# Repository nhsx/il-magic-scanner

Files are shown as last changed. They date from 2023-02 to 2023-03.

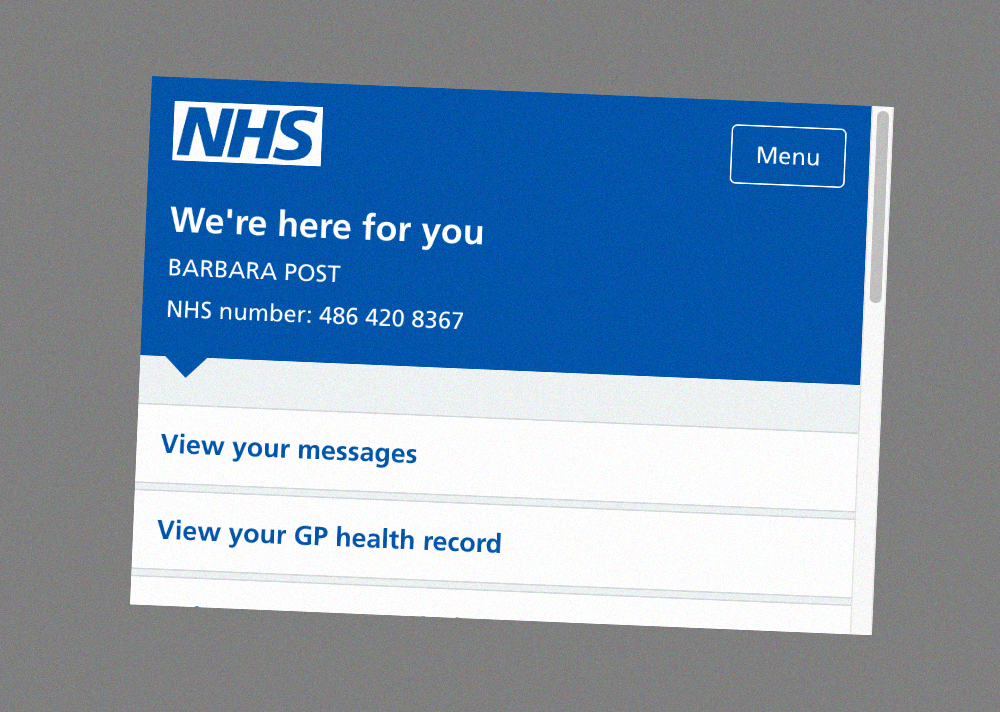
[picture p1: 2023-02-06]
piscanner/fakes/scan.png

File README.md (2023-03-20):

# The Magic Scanner

In this project, we built a portable scanner to test the idea of
scanning patients in to a hospital Patient Administration
System (PAS) with their phone without having to make changes to
the NHS App. The scanner takes an picture of the app home screen,
processes the image using optical character recognition (OCR),
and outputs the text in a format that can be easily consumed by
the PAS. We used a Raspberry Pi and a Pi camera module to build
the scanner, and trained the OCR model using the PyTesseract
library.

We were able to demonstrate that it is possible to build a
scanner like this with a small team on a tight timeline. The
project also highlighted the range of capabilities, equipment,
skills, and tooling required to build such a device, which could
be useful for future projects. However, further testing is needed
to assess the reliability of the scanner in practical use, and
the OCR model may need to be retrained with better training data
specifically to address potential ethnic bias issues.

## Setting The Scene

When you walk into A&E, the very first interaction you will have is
with the triage desk.  The hospital needs to know who you are.  Apart
from any administrative checkpointing, what the hospital want at that
point is a route in to your medical records.

The conversation that tells A&E who you are sounds simple, but it can
hide frustrating complexity.  Just the first question they'll ask -
what is your name? - can go down a rabbit-hole of misheard accents,
uncommon spellings, and unexpected cognitive difficulties.

Obviously a name alone isn't enough to identify someone.  They'll ask
for your date of birth, too, but even then, clinical mistakes have
been made where the same name and birthdate are shared by two
individuals.

To ensure they have identified *you*, and not someone else who happens
to have your name and birthday, what they really want is your NHS
Number.  But it is a rare patient who will know that off the top of
their head, or who will bring a GP letter with them to A&E.

Our hypothesis was this: if we can scan the information that the
triage desk wants out of the patient's phone, rather than have them
narrate it, we can solve three problems: first, the slow, face-to-face
"no, spelled with an 'E', two 'L's" conversation is short-cut; second,
we can bring additional information to the interaction in the form of
the NHS Number; and third we can get it right first time.

### The Patient ID QR Code

We want the NHS App to present a QR code containing the relevant
information, on the home screen.  QR scanners pretend to be a USB
keyboard: when you scan a QR code, to the computer it's as though
someone was sat there typing in the data encoded in the QR code.
And when you sign in to the NHS App with an NHS Login that is
sufficiently assured, it has all the information we want to
present. All the technical parts are straightforward.

However, if we want to make a change in the NHS App, that
effectively means rolling it out nationally.  We don't have the
cohorting ability to only roll out the QR code to people who are
going to turn up at a specific A&E: in general people don't
schedule falling off their ladders for us, convenient though that
would be.  That means we'd be introducing a potentially confusing
feature into the system before anyone could either explain what
it was.

Without being able to get a QR code into the NHS App itself as a
trial, the next most obvious option is that we stand up a
parallel service to generate the QR code.  This service would be
fronted by NHS Login, so people could use exactly the same
credentials as they use for the NHS App, and it as only purpose
would be to put a scannable code on the phone's screen.  This
would be technically simple to build and operate, but it turns
out that there's no way to implement this without causing a new
delay as the user signs in to this new service.  Using the same
credentials doesn't grant access to biometric login.

So this approach is largely ruled out.  We can't risk making things
worse otherwise no hospital is going to be interested in helping us to
run the trial.

### Or Not

And that's how we end up with this repository.  The fundamental
question we want to answer has nothing to do with QR codes, and
everything to do with the ergonomics of scanning the phone.  As long
as we can test "patient approaches desk, scans phone, is signed in"
and the timings around it, it doesn't matter what's shown on the
phone's screen.

So, we thought, why don't we just read the data off the home screen of
the app?  It has the name and the NHS Number, it's a known layout.
Can we design a scanner which will pluck that off the screen and
present it as though it *was* scanned by a barcode reader?

This repository is the code, CAD, data, and documentation of that
scanner.

## The Magic Scanner Operating Principle

We know that the scanner needs to:

1. Take a photo of the screen
2. Identify where the data we want is
3. Do some character recognition to turn right parts of the photo into text
4. Send that text to a USB host, as fake keypresses

And it has to do all that in a short enough time period that the
reception staff don't get annoyed with it or think it's broken; and it
has to be cheap enough that we'd be able to build a few of them
without breaking the bank.

Of all the steps, step 2 intrigued me the most.  That sort of object
recognition and bounding box extraction is a classic machine learning
task, and how well we could perform that job would put a limit on the
quality of data that the scanner would present to the user.

My first thought was to give a Raspberry Pi a try.  They have several
things going for them, most importantly for this project a) good
camera and USB gadget support; b) excellent software availability and
community activity; and c) I had a Pi Zero 2 sat next to me.

The importance of point c) shouldn't be underestimated.  We needed to
demonstrate that we could build a working prototype to test the
software and the ergonomics in days, not weeks, and having hardware
available off-the-metaphorical-shelf enabled us to go from idea to
first physical prototype between the Thursday of one week and Tuesday
the next.  Further refinement and a mk2 followed.

There were questions in my mind while making that choice, though: for
instance, would the processor in the Zero 2 have enough power to run
the machine learning model?

## The Build

### Physical Shell: the Mk1

Unfortunately the licensing situation in this project doesn't let me
share the original FreeCAD model itself, but I've put the `.step` file
[here](cad/piscanner-mk1.step) and the `.stl` (which github will
render for you as a pretty picture) [here](cad/piscanner-mk1.stl).
The reason is that the CAD model has a dependency on some third party
`.step` files that I don't have a licence to distribute.  When I get a
chance to come back and clean up the dependencies I will be able to
share the FreeCAD document, but until then, this is the best I can do.

There are a couple of things to note about the design of the mk1, both
good and bad.

#### 1. The Trigger Mechanism

I needed a button press to trigger taking the photo and processing it.
In my first version I thought it best to hide the button and see if I
could make the physical interaction as simple as possible.  In this
version there is a pair of buttons mounted under the window that the
Pi's camera peers through, such that when you press the phone
face-down onto the window, the window frame flexes and allows contact
to be made.  It's a mechanism which puts the phone screen at a
well-controlled distance from the camera lens.  This is important,
because the Pi Camera Module v2.1 is fixed focus.  They come from the
factory with a focal point out at infinity, and need to be refocused
to take good pictures of close objects.  The scanner needs not to be
too tall so I refocused the lens almost as close as I could, but until
I'd built the thing I didn't have a good way to check how much depth
of field I had to work with.  So this mechanism let me ensure that the
screen was in a precise place when the buttons were pressed.

If I were to build this mechanism again, there is a change I'd make in
that the current design puts the buttons on top of a pair of towers
attached to the base.  That attachment point is fine - I intentionally
wanted to be able to pull all the electronic guts out without too much
stress because I knew I was likely to want to change it around - but
the change I would make is to make the towers removable.  The distance
you need to depress the buttons I used to get a contact is sub-mm, and
the dimensional stability of the 3d printing process I used to make
the shell isn't great for this sort of design.  I wanted to be able to
swap out the towers to tweak their heights so the offset from the
flexible frame was better, but couldn't.

#### 2. The Absence Of Any Feedback Whatsoever

In the time available I just didn't have the opportunity to put any
status lights or readouts on the outside of the device.  I knew how I
was going to, it just fell outside the scope of a quick prototype
whose purpose was to prove the data pathway.

#### 3. The Raspberry Pi mounting

Rather than figure out the dimensions of a raspberry pi zero, I
figured that I could just reuse an existing case and clamp that into
place, giving me a single thing to position correctly on the base of
the scanner than having to worry about separately mounting the pi and
its attached camera.

This was a mixed blessing: the
[case](https://www.raspberrypi.com/products/raspberry-pi-zero-case/)
obviously fits the parts perfectly, but is a rather interesting shape,
which made cutting an accurate slot for it in the model something of a
challenge.  If I'd had a rather more rectilinear case to hand I would
have used that instead and simplified the job.

#### 4. Other flaws

In my rush, I underestimated how much clearance a USB plug needs.
There's not nearly enough clearance inside this body for a
conventional USB-micro plug to fit, and I ended up cutting a hole in
the wall for the USB keyboard cable.

There are a few other design details I could have done better and
suspected were a problem at the time, but sort of got away with.  The
mating interface between the base and the upper shell made the upper
hard to 3d print, for instance, and the attachment point for the
flexible window frame didn't have enough vertical bracing so the angle
of the window was dependent on the tightness of the bolts holding it
on.  Not ideal.

Purely by chance, at no point in the lifespan of the mk1 did I need
access to the SD card.  Lacking any way of getting at it which
wouldn't involve a complete disassembly was a conscious choice, but
one I would rectify later.

### Machine Learning

The scanner needs to be able to pull out small, specific chunks of the
pictures it takes, so that it can feed them to optical character
recognition software.  As I said above, this is an absolutely classic
machine learning task, but just knowing that it's possible is a world
away from having a working implementation that does the thing when you
press the button.

I simplified the problem of going from idea to implementation by
restricting the type of model I would look at to the YOLO family.
These are very fast, accurate enough object recognising neural network
systems that are popular enough in the industry that the tooling and
support around them is very good.  This meant that I had a choice of
implementation tooling.

Based on the availability of samples and documentation, I picked
`darknet` as a training platform and, initially, as the inference
platform that the scanner would execute when the button was pressed.

There is a terraform script for provisioning an AWS GPU instance (I've
picked `g3s.xlarge` as the cheapest spot instance size available) in
[here](gpu-terraform). It takes care of grabbing the
`darknet` source and building it.  Note that it *also* provisions a
smallish jump host as a non-GPU instance so that you can have a stable
jumping-off point that's not so expensive to run.

#### Model Selection

To cut a short story even shorter, given the time constraints I didn't
want to mess about trying to find a network architecture that would
work, I needed to pick something off the shelf that I could reuse
without too much hassle and would have enough power, and the right
inputs and outputs, for the task.  The YOLO family of network
architectures fit the bill, and specifically the YOLOv4-tiny variant
looked like it would have the performance characteristics we need.
It's also popular enough that there is a lot of guidance available
online for using it. There's a premade `darknet` config for it, so it
looked like it would be reasonable to start there and only change that
decision if it turned out either to be too slow, or not accurate
enough.

#### Training Data

We want the network to be able to put a bounding box around two items
of text on the phone screen: the patient's name, and their NHS number.
Given the constraints of the physical device, there's actually not
much variation we should expect in the pictures we'll be putting
through the network.  The home screen of the NHS App is very
constrained, visually speaking: it's a consistent font, there are very
consistent markers around the image, colours should only be in a
certain range, and so on.  That makes the job of putting together a
training data set simpler than it might otherwise be.

We're also helped here by a very useful technical detail: the NHS App
is (to simplify slightly) just a web site.  You can visit the site
online in a browser, and you can view the source.  If you resize the
browser window to be mobile phone shaped, it renders the same as if it
was on a phone.

So, I did that, grabbed the resulting web page, and saved it.  I then
edited the HTML to replace my name and NHS number with [python
template
markers](https://docs.python.org/3/library/string.html#template-strings).
That enabled [this
script](training-data-generation/generate_sample_html.py) to generate
an arbitrarily large number of fake NHS App home screens, each with
their own name and number.

Next, I used [this
script](training-data-generation/generate_screenshots.py) to take
screenshots of each fake with
[selenium](https://selenium-python.readthedocs.io/).  It's not just
the screenshot you need, though: to train the network to put the
bounding box in the right place, you also need to capture where the
bounding box is.  Fortunately that's made available by the browser
API, so we can directly read the bounding box out and save it to a
JSON file.

If you've been following along, you'll now have a directory full of
screenshots of the NHS App homepage, along with the bounding boxes of
where the information we want is.  That's all well and good, but we
need our scanner to be robust to the sorts of noise and distortion
that taking a photo of a phone screen under only semi-controlled
conditions will be subject to.  For this, I leaned on the
[albumentations](https://albumentations.ai/docs/#getting-started-with-albumentations)
tool.  [This
script](training-data-generation/generate_augmentations.py) is what
drives it, and you can see the list of different types of distortion
it applies for me:

```
[
    A.ShiftScaleRotate(shift_limit=0.0625,
                       scale_limit=0.5,
                       rotate_limit=10,
                       border_mode=cv2.BORDER_CONSTANT, value=(128,128,128),
                       p=0.75),
    A.GaussNoise(),
    A.Blur(blur_limit=3),
    A.OneOf([
        A.OpticalDistortion(p=0.3),
        A.GridDistortion(p=0.1),
    ], p=0.2),
    A.OneOf([
        A.CLAHE(),
        A.RandomBrightnessContrast(0.5)
    ], p=0.3),
    A.HueSaturationValue(p=0.3)
]
```

So that's a selection which simulates a few different ways the phone
can be out of position, or registering funny colours, or dirty, and so
on.

I generated many, many training images.  90,000, in fact.  This turned
out to be far too many to be practical and far more than was needed,
but at that point I reasoned that it was better to aim high because I
could always use a subset.

#### Training

Mechanically, the process of training was a matter of uploading the
training data into AWS and getting it onto a GPU instance, then just
running `darknet` with the right parameters.  A word to the wise:
generate the training data where you're going to do the training.
Don't put yourself in the position of needing to upload 5GB of images
over residential broadband.

ANYWAY.

The YOLOv4 architecture learned from this dataset *fast*.  Fast is
relative, but I had a usable network for testing with in half an hour
or so, and in slightly more than an hour `darknet` reported it was
done. Nowhere near the overnight runs that I was expecting.

From this I can intuit that the YOLOv4 architecture is *dramatically*
overpowered for this use case.  The question is whether this matters.
More on this shortly.

### USB Tomfoolery

Taking a brief break from the world of machine learning, there are a
couple of prosaic interface concerns which I needed to deal with.  One
of these is the need to replicate the data flow of a handheld QR code
scanner: to get the data across a USB cable, as though typed into a
keyboard.

Fortunately, making this simple is the Raspberry Pi Zero 2 hardware.
It has two micro-USB ports, one of which supports USB-OTG, which is
what a USB port needs to support if you want to connect it as a USB
*device*, rather than as a USB *host*.  Once set up as a USB gadget,
whether the USB host at the other end of the USB cable is detected as
a hard drive, a modem, or a keyboard is a matter of software
configuration.

Now, that's only half of the story.  When you think of sending data
and pretending to be a keyboard, it's clear that you can't just send
arbitrary data.  You can't send a `NULL`, for instance: there's no key
for that on the keyboard.  So we need a conversion that takes data,
and converts it into the corresponding keypresses.  Fortunately for
our purposes, the conversion is easy in that we only need to be able
to send things that are typeable: a name, a number, and some spaces.

In [this repository](https://github.com/nhsx/il-keebd) is a service
that runs on the raspberry pi whose job it is to take data (from
something else running on the machine), strip out anything it can't
pass on, and convert the remainder into keypresses.  It's not very
general, in the sense that there's a lot that in theory is typable
which it ignores, but it does enough for our purposes and is
extensible if a need surfaces.  It's standalone enough that I've spun
it off as its own project; I'm sure it'll come in handy in other
circumstances.

## Mk2

### The Hardware

Having shown the mk1 to the team, there were several changes that
needed making.

The flex plate to trigger the button was deemed too much of a leap:
while it's a neat mechanism, people can be hesitant to touch their
phone screens to anything.  And if the screen is cracked, it could
actually cause the image to be corrupted in a way that neither the
phone's owner nor the person on the other side of the desk could see
to know that anything was wrong.  So that went, replaced by a button
on the outside of the case for the reception staff to press.

The lack of a visual feedback mechanism was also a problem, so I
planned to add a row of LEDs.  That's a fairly straightforward change:
more below.

There were a couple of other tweaks to make the case easier to 3d
print.  I redid how the upper shell and the base to which the
electronics are mounted mate together, for a start: the mk1 needed
rather a lot of support material in the print, and that's a waste of
material if it can be avoided.  The aren't any internal columns on
this version, and there's a proper clearance hole for the USB cables.

I also added a vanity plate with our unofficial team logo, because -
well, why not.

As with the Mk1, I can't share the FreeCAD file just yet, but
[this](cad/piscanner-mk2.stl) is what it looks like (`.step`
[here](cad/piscanner-mk2.step)).  It has a footprint a little larger
than the mk1 to accomodate some additional electronics.

### Blinkenlights

Mk1 of the scanner had no feedback mechanism, and that was a problem.
Fortunately adding status LEDs is a fairly straightforward
proposition: there is a very cheap board [you can
get](https://www.amazon.co.uk/Interface-Controller-Compatible-Ardu-ino-Raspberry/dp/B08ZKSYZJ4)
which is designed for lighting LEDs in interesting patterns, which you
can plug it into the I2C pins of a raspberry pi's GPIO interface and
talk to it over a simple API.

I couldn't find any direct support for the PCA9685 board aimed at the
raspberry pi, but there's support in the
[micropython](https://micropython.org/)
[ecosystem](https://github.com/adafruit/micropython-adafruit-pca9685).
I
[shamelessly](https://github.com/adafruit/micropython-adafruit-pca9685/blob/master/pca9685.py#L5)
[nicked](https://github.com/nhsx/il-magic-scanner/blob/main/ledd/ledd/pca9685.py#L22)
the support code and wrote a [very thin
shim](https://github.com/nhsx/il-magic-scanner/blob/main/ledd/ledd/pca9685.py#L11)
to reuse it so I didn't have to figure out how to drive the PCA9685
directly.

With that in place, I hooked a red, a yellow, and a green LED up to
the PDA9695 board to give me some feedback channels.

There was the option here to design a custom PCB to hold both the
PCA9685 controller and the LEDs.  That might be suitable for a future
iteration, but for now the LEDs are hand-soldered through-hole
components on prototype board.  As and when we produce any more of
these, I can revisit that.

In terms of the software side, as with the keyboard support it made
sense to bundle up the thing driving the LEDs up separately to the
software doing the actual scanning, but for a slightly different
reason: if the scanner bit fails, I still want control over the LEDs
so I can blink my little red blinky light.  The code is [here](ledd);
I've not split it out to a separate project for the simple reason that
the bits of config that tell it what various patterns of lights mean
are super-specific to the business of being a scanner, and I haven't
got a clear picture in my head of how to separate that out well.

### Tying It All Together

So, with all those preparatory bits out of the way, onwards to the
main body of code.

On my first pass through, while I was trying to get the mk1 working, I
was using `darknet` itself at inference time, when trying to pull the
data out of the photo the scanner takes.  It turns out that, for
whatever reason, `darknet`'s inference mode was taking about a minute
to return any results when run on the Raspberry Pi, when the same
network and input image took 0.3 seconds to resolve on a laptop.  I
never figured out why: yes, there should be a difference, but that
wide a difference specifically on a network architecture designed for
use on edge devices was just odd.  I suspected that it was down to
`darknet` itself not being optimised for that architecture, rather
than the design.  At least, I hoped it was.

Fortunately, it proved straightforward to check.  OpenCV has a neural
network implementation called DNN which, it happens, is capable of
loading networks that darknet has trained.  Running the same network
and image through that library got the inference time down to 10
seconds.  Good, but still not quite good enough for practical use.

The network I initially trained was based on a YOLOv4 example, and had
an input network size of 416x416 pixels.  I thought that by reducing
the image size I might get some more speed, so I spun up another GPU
instance in AWS and trained a network with an input resolution of
224x224 pixels.

This worked better than I hoped: it trained faster than the 416x416
pixel version, and when transferred over to the raspberry pi, the
inference time, run through cv2.dnn, dropped to below three seconds.
Given the reduction by 75% in image size over the previous version,
for that to result in a run-time 25% of what it was is about the best
result I could have hoped for, and pushed the performance of the
scanner into the range of suitability for practical use.

The final piece of the puzzle, then, is a script to coordinate all the
parts I've built.  It's in [this directory](piscanner/).  In there you'll
find the main scanner service code which:

- waits for the button press
- takes a photo from the main camera when it's triggered
- processes the photo and passes it through the neural network
- extracts the interesting regions
- passes them to an OCR application to convert them to text
- pushes that text over USB to anything plugged in at the other end
- serves up a diagnostic page over HTTP so you can see what it's doing
- makes lights flash in visually stimulating and informative ways at
  various points along the way

There's also the accompanying systemd config to make the service start
up at boot time, as with the other services in this project.

Note that what you *won't* find in there are the model weights, the
data file that defines the neural network.  That's because it's 22MB
of stuff that doesn't want to be versioned as a lump in this
repository.  You'll find it over in the `Releases` instead.  See
`[piscanner/README.md](piscanner/README.md)` for instructions on how
to set up the weights file, and all other things related to actually
running the `piscanner` code.

### Developer Conveniences

#### Wifi

It's very useful to be able to connect to the scanner over the network
to diagnose what it's up to and to observe it working (or not).
However, in a lot of the places we work, it's not possible to connect
arbitrary raspberry pi's to the wifi to allow that to work.  Looking
at you, GovWifi.[^2]

It turns out that there's a fairly simple alternative, and that's for
the scanner to run its own access point.  With the right
configuration, the scanner presents itself as a hotspot that you can
connect to, with no further connectivity onwards to the internet but
enough of a network to allow you as a developer to connect to the
scanner and to do what you need to do.

[This directory](pi-ansible-config/roles/hostap) contains the scripts
which will configure any old raspberry pi to do this.  You can switch
between access point and ordinary network client mode (with a reboot,
but that's fine for now) and as long as you do that switch before you
leave somewhere with friendly wifi, all is well.

I'll need to revisit this as and when we have more devices in the same
location.  Having each one advertise its own AP isn't ideal in that
situation; I can see that I might well want them to join a specific
debugging AP run from a separate device.  But for now, it works.

#### Test screens

If the purpose of the scanner is to inject data into the hospital PAS
screen, it's useful to be able to demonstrate what that would look
like.  [This directory](piscanner/public/pas) contains a very
straightforward HTML mockup of the patient search screen of a
hypothetical PAS, using the [NHS Frontend
Toolkit](https://nhsuk.github.io/nhsuk-frontend/) to make it look
good.  It's served over the local network when the scanner is running
so if you want to demo it, you can.

Rather than add a new service to a growing system, I decided to serve
this from the same process that's doing the scanning.  It's all
handled by python's asyncio framework.

#### Development tools

The Raspberry Pi Zero 2 is a perfectly competent little computer, and
doing the code development on the scanner itself over an SSH
connection was a painless experience.  [This
directory](pi-ansible-config/roles/dev) contains installation scripts
for the small number of tools I used to do so.  My intention was that,
when combined with a backup/sync script on my laptop, I would be able
to shift development onto another Pi without any effort and largely
that remains true.

## Conclusions: what did we learn?

### The Trees

There are two main issues that want folding into the next iteration.
First, the bounding box training was a little bad: when
`albumentations` does its job of adding noise to the image, one of the
things it can do is to translate it so the name isn't completely on
the screen.  That's also something that can happen In Real Life just
by someone mis-aligning their phone.

The behaviour of `albumentations` when this happens is to clip the
bounding box at `x=0`, no matter how far in the negative direction the
edge of the bounding box should be.  This means that the neural
network learned that it was OK to clip the bounding box straight
through the middle of a letter, under certain circumstances, which is
something that the OCR isn't good at handling.

The fix for this is straightforward: we want to simply reject scans
where the information we want isn't on the screen.  Removing the
bounding boxes for any that have been clipped offscreen from the
training data, and retraining, would do the trick here.  It's better
to force a rescan than proceed with partial data if we can detect it.

The second issue is that there is a horrible, no good, very bad
problem with the training data that I am aware of but haven't yet
corrected.  The name generator that I used for this was very... white.
I might very well have trained this system to be very good at
identifying, for instance, "Jeff Smith" but extremely unreliable at
picking out a "Mohinder Singh" or a "Jo Ng".  What I *hope* is that
the model has learned that what matters is *where* letters are, not
*what* they are, but this really, really needs testing - or better,
just coming back and redoing once I can identify a much better source
of training data than I had at the time.  Alternatively I could drop
the idea of "names" altogether and train on random character
sequences.

### The Wood

In terms of the primary goal of the project - can we build a scanner
that will let us test the ergonomics of our proposed feature without
having to get that feature into the NHS app - we can say that yes, we
can.  At this point the scanner has not had the larger-scale in-situ
testing that would let me assess whether the scanning is reliable
enough in practical use.  While we do need to do that, and going
through that process will doubtless lead to changes needed both to the
physical design and the software it runs, getting to this point alone
within a two week sprint (actually slightly less - 10 calendar days
from breaking ground on the mk1 to demoing the mk2 as a working
artefact), we can say that as a design and build process it has been a
success as far as it went.

Taking a step back from this project itself, demonstrating that the
range of capabilities, equipment, skills, and tooling required to
build a device like this is well within the grasp of a very small team
on tight timescales is in its own right a valuable outcome, and puts
a useful frame around the sorts of projects that we can consider for
the future.

## Author

Alex Young <alex.young12@nhs.net>

[^2]: I'm probably being unfair.  It's not unlikely that this can be
    made to work if you know the right combination of settings, but I
    spent an afternoon poking at it with no luck.  And even if I *had*
    managed to get the scanner onto GovWifi, it still wouldn't be
    accessible to a laptop sat next to it because the network is
    designed (quite rightly) to segregate clients.

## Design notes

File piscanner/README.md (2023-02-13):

# piscanner

This is the service which coordinates the primary functionality of the
[magic scanner](https://github.com/nhsx/il-magic-scanner).

It is a Python service, written to be run under the system Python on
Raspberry Pi OS Bullseye (currently 3.9.2).

## Installation

### Package dependencies

`piscanner` is designed to work with the system python, so relies on
system python packages.  They are installed by the
[ansible](../pi-ansible-config) scripts, but for reference the
packages you will need are:

```
$ sudo apt install \
	ffmpeg \
	python3-picamera2 \
	python3-gpiozero \
	python3-tesserocr \
	imagemagick \
	python3-aiohttp \
	python3-websockets \
	python3-opencv \
	python3-smbus \
	i2c-tools
```

### Service dependencies

Before attempting to run `piscanner`, make sure you have installed the
`[ledd](../ledd)` and `[keebd](https://github.com/nhsx/il-keebd)`
services and have them running at boot.

### piscanner itself

Run:

```
$ sudo make install
```

This will copy the Python source to `/opt/piscanner/`, and install a
`piscanner.service` systemd unit.  You can use `systemctl` to start
and stop the service in the usual way (that is, `sudo systemctl start
piscanner` will start the service).  It will start at boot.

Once you have installed the service, you will need to separately
download a `.weights` file from
[here](https://github.com/nhsx/il-magic-scanner/releases/tag/v1) and
put it in the right place.

To download and install the weights file, run:

```
$ cd /tmp/
$ wget https://github.com/nhsx/il-magic-scanner/releases/download/v1/scanner-yolov4-tiny_final.weights.bz2
$ bunzip2 scanner-yolov4-tiny_final.weights.bz2
$ sudo mv scanner-yolov4-tiny_final.weights /opt/piscanner/model/backup/
```

## Hardware config

### The camera

You will need a camera module plugged into the pi.  I used a v2.1.
With a v2.1 camera module you can manually set the focal length.  See,
for instance,
[here](https://projects.raspberrypi.org/en/projects/infrared-bird-box/6)
for instructions on how to do this.

The camera module v3 has autofocus, and I haven't tested this to know
whether it works in our application.

### The Button

The `piscanner` script expects to be triggered by a button press.  The
button should be momentary push-to-make, and connected between [GPIO
pin
17](https://projects.raspberrypi.org/en/projects/physical-computing/1) and GND.

### The LEDs

See [here](../ledd) for hardware information on connecting the LEDs.

### Power

The raspberry pi will need its own power supply.  Use an official
Raspberry Pi power supply plugged into the `PWR` port.

### USB cable

Plug a USB micro cable between the other USB micro port on the pi and
a USB port on the computer you intend to receive scanned data.

## Usage

With the `piscanner` service running, to scan a phone:

- On the receiving computer, put the keyboard focus in a text input
  element.
- Log in to the NHS app, and if necessary navigate to the home screen,
  scrolled to the top.
- Orient the phone so the upper portion of the screen, with your name
  and NHS number, is visible to the camera and upright.
- Press the scanner's button.  You should see indication from the LEDs
  that it's processing the image.
- If the scanner was able to extract name and number, you will see
  these typed into the text input element on the receiving computer.

## Author

Alex Young <alex.young12@nhs.net>

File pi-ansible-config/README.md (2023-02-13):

# Piscanner Ansible Config

This is an Ansible config to bring a fresh Raspberry Pi OS image up to
a state where development can happen on it, it can run the
[piscanner](../piscanner) and associated services, and it can run its
own WiFi access point so that you can get an SSH shell without needing
to configure the scanner to join an existing WiFi network.

You will need:

1. A Raspberry Pi.  I used a Zero 2.  You *may* have luck with a 3A+,
   a 3B+, a 4, or a 400.  I haven't tried any of them.
2. An SD card.  I use Samsung Edge A1 cards, because they're nice and
   fast without being horrid and expensive.

## Usage

### Install ansible

First, install `ansible`.  That's platform-specific and beyond the
scope of this README.

### Configure and Install Raspberry Pi OS

Using the [Raspberry Pi
Imager](https://www.raspberrypi.com/software/), click `Choose OS` and
select `Raspberry Pi OS Lite (32-bit)` from the `Raspberry Pi OS
(other)` menu.  Click the cog button that appears, to bring up the
advanced options menu.  You will want to allow Imager to pre-fill
your wifi config.

Set the hostname to `piscanner`.  The `ansible` config assumes this is
the hostname you've set.  If for some reason you can't use that
hostname (say, you've already got something on the network with that
hostname, or you're doing more than one of these), then pick a name
here and make sure to edit the file called `hosts` so that it matches
whatever you pick.

Enable SSH. It's best to use public-key authentication only, but you
do want to set a password for the `pi` user.

Under the `Configure wireless LAN` section, make sure that the
`Wireless LAN country` setting is correct.

Click `Save`, and plug in an SD card if you haven't already.  `Choose
Storage` to select that card, then `Write`.  At this point you have
enough time to go and make a cup of tea.

### Drink tea

Drink your tea.  It is important that you do not rush this step.

### Boot the Pi

Once you have finished your tea, because you took the correct amount
of time to do so, the write will have finished.  Extract the SD card
from the machine you've used to image it, plug it into your Raspberry
Pi, and switch it on.

When you boot it for the first time, it will take a significant length
of time to appear on the network because it needs to resize the
filesystem for the SD card on the first boot.  On OS X and a compliant
network, I find it useful to run this in a console while that's
happening so I know when it's ready:

```
$ while ! ping piscanner.local; do echo "not yet"; done
```

What that's doing is repeatedly trying to look up the `piscanner` host
on the local network.  When the Raspberry Pi has got far enough
through its boot sequence that it can successfully connect to the wifi
network you configured in the Imager, it'll start responding to pings.

### Run ansible

If the pi is responding to pings, that means you can SSH to it, and
that means `ansible` can run.  I've provided a `Makefile` to simplify
this a little. Run:

```
$ make first
```

This will prompt you for a sudo password, which you will only need to
provide the first time you run `ansible`.  Subsequent runs, if you
change the config, can be run simply as:

```
$ make
```

Since the first execution of `ansible` has some work to do, you may
find that this is an appropriate juncture for more tea.

## Wifi Access Point

As mentioned above, the scripts in `roles/hostap` will configure the
pi such that it can offer its own wifi access point.  Once `ansible`
has been run the first time, the scripts to switch between wifi access
point mode and client (or "station") mode are at
`/usr/local/sbin/become-hotspot` and `/usr/local/sbin/stop-hotspot`.
You will need to reboot the pi after running either to switch mode
back and forth.

### Enabling the hotspot

To enable the inbuilt hotspot, connect to the pi and run:

```
$ sudo /usr/local/bin/become-hotspot
$ sudo reboot
```

You will be unceremoniously disconnected.

A short time later - 25 seconds or so - if you open your network
control panel you will be able to see a new SSID available to connect
to, called `piscanner-123`.  Connect to it with the passphrase
`comeonbarbieletsgoparty`.  Once connected, you will be able to
reconnect to the piscanner by running:

```
$ make sh
```

You will want to enable the inbuilt hotspot any time you are going to
take the pi anywhere it won't be able to join an existing network.

### Disabling the hotspot

To switch from the inbuilt hotspot to a predefined network, connect to
the pi and run:

```
$ sudo /usr/local/bin/stop-hotspot
$ sudo reboot
```

As before, your SSH connection will be killed, and a short time
later - 25 seconds or so - you will be able to run `make sh` to get a
new one.

## Backups

If you're doing significant work on the pi (which you can), you'll
want to be able to sync that work off the pi.  To that end there's a
`make backup` task you can run to sync `~/src` off the pi into a local
`backup/` directory.

## Author

Alex Young <alex.young12@nhs.net>

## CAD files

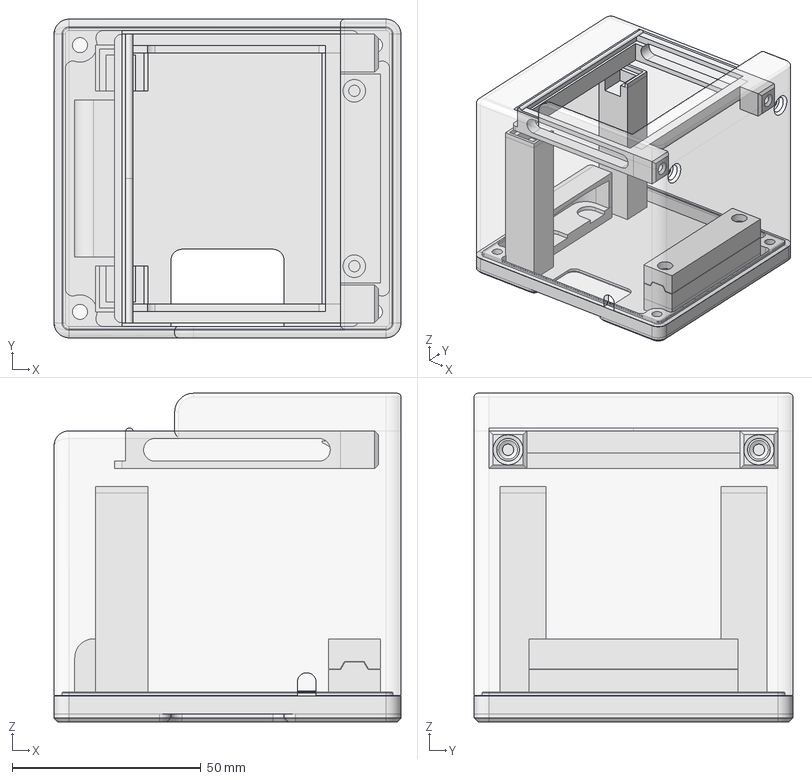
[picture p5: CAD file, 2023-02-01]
cad/piscanner-mk1.step
92.0 x 84.5 x 87.1 mm
Slice.0
Slice.2

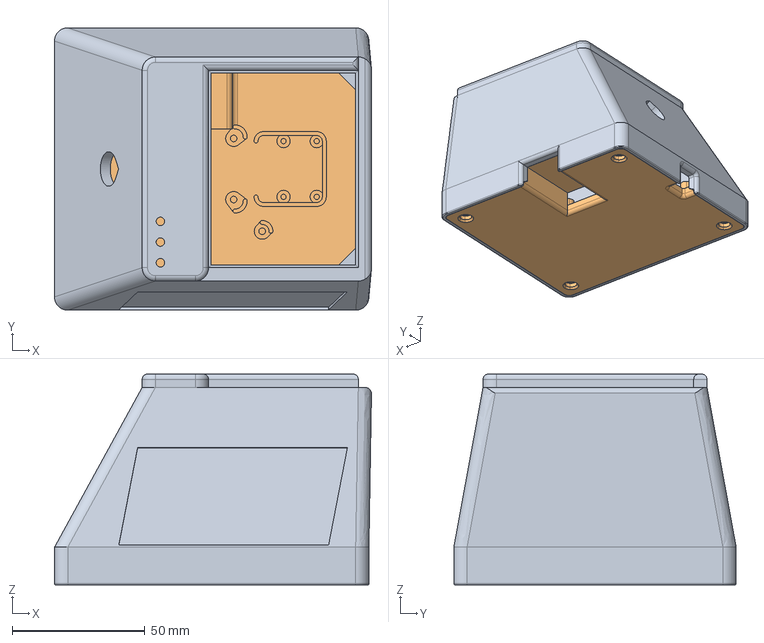
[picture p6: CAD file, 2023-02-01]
cad/piscanner-mk2.step
119.4 x 106.4 x 79.5 mm
UpperBody
BaseBody

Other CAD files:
cad/piscanner-mk1.stl
cad/piscanner-mk2.stl

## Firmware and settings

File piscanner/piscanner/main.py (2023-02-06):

#!/usr/bin/env python

from gpiozero import Button

import asyncio
import logging
import sys
import json
from pathlib import Path

from .inference import Inference
from .graphics import overlay_rects, extract_subimages
from .camera import Camera
from .ocr import CliOcr, FastOcr
from .web import run_web_app, schedule_update
from .output import KeebdOutput

class App:
    def __init__(self, storage_path, button, camera, inference, ocr, output, state_output, logger):
        self.storage_path = storage_path
        self.button = button
        self.camera = camera
        self.inference = inference
        self.ocr = ocr
        self.output = output
        self.logger = logger
        self.state_output = state_output

        self.button.when_pressed = self.cv2_entrypoint 
    
    def img_path(self, name):
        return self.storage_path/f"{name}.jpg"

    def cv2_entrypoint(self):
        self.logger.info("button pressed")
        asyncio.run(self.callback_with_cv2())
            
    def pick_detection(self, detection_list):
        if len(detection_list) == 0:
            return None
        else:
            return sorted(detection_list, key=lambda det: det.confidence)[-1]

    async def callback_with_cv2(self):
        await self.state_output.processing()
        name_path = self.img_path('name')
        number_path = self.img_path('number')
        screen_path = self.img_path('image')
        
        self.logger.info("Image capture started")
        full_size_image = self.camera.take_pil_image()
        self.logger.info("Image captured, starting inference")
        detections = self.inference.infer(full_size_image)
        self.logger.info("Inference done, selecting detected areas")

        selected_name = self.pick_detection(detections['name'])
        selected_number = self.pick_detection(detections['number'])
        if selected_name and selected_number:
            resized_for_display = full_size_image.resize((820, 616))
            name_image, number_image = extract_subimages(resized_for_display, 
                    [s.norm_rect() for s in (selected_name, selected_number)])

            name_image.save(name_path)
            number_image.save(number_path)
            overlay_rects(resized_for_display, 
                    [s.norm_rect() for s in (selected_name, selected_number)])
            resized_for_display.save(screen_path)

            self.logger.info('images extracted')

            ocr_jobs = (self.ocr.read_name(name_path), 
                self.ocr.read_number(number_path))
            decoded_name, decoded_number = await asyncio.gather(*ocr_jobs)

            self.logger.info(f"Read: {repr(decoded_name)} {repr(decoded_number)}")

            await asyncio.gather(self.output.send(decoded_name, decoded_number),
                   schedule_update({'name': decoded_name, 'number': decoded_number}),
                   self.state_output.success())
            self.logger.info("Client notified")
            

        else:
            await self.state_output.ready()
            if not selected_name:
                logger.info("No name found")
            if not selected_number:
                logger.info("No number found")

class LEDDStateOutput:
    def __init__(self, logger):
        self.logger = logger

    async def _set_state(self, state_name):
        self.logger.info(f"setting state {state_name}")
        proc = await asyncio.create_subprocess_exec(
                "/usr/local/bin/ledd-set-state", 
                state_name,
                stdout=asyncio.subprocess.DEVNULL,
                stderr=asyncio.subprocess.DEVNULL)
        await proc.communicate()

    async def _go_to_ready_after_delay(self):
        await asyncio.sleep(3)
        await self.ready()

    async def start(self):
        return await self._set_state("start")

    async def ready(self):
        return await self._set_state("ready")

    async def processing(self):
        return await self._set_state("processing")

    async def success(self):
        await self._set_state("success")
        await asyncio.sleep(3)
        await self.ready()

    async def alert(self):
        return await self._force_state("alert")


logger = None

async def exec(argv):
    global logger

    quarter_size_settings = {
            'cfg_filename': 'model/scanner-224/scanner-yolov4-tiny.cfg',
            'weights_filename': 'model/scanner-224/backup/scanner-yolov4-tiny_final.weights',
            'input_dims': (224, 224)
            }

    class_labels = ['name', 'number']

    settings = quarter_size_settings

    logging.basicConfig(format='%(asctime)s - %(name)s - %(levelname)s - %(message)s')
    logger = logging.getLogger()
    if '--debug' in argv:
        log_level = logging.DEBUG
    else:
        log_level = logging.INFO
    logger.setLevel(log_level)
    logging.getLogger('picamera2.request').setLevel(logging.WARN)

    state_output = LEDDStateOutput(logger)
    await state_output.start()

    logger.debug("Loading inference")
    if '--fake-inference' in argv:
        inference = Inference.fake(class_labels)
    else:
        inference = Inference(settings['cfg_filename'], 
                settings['weights_filename'], 
                settings['input_dims'], 
                class_labels)
    logger.debug("Inference loaded")

    logger.debug("Loading camera")
    if '--fake-camera' in argv:
        camera = Camera.fake('fakes/scan.png')
    else:
        camera = Camera()
    logger.debug("Camera loaded")

    if '--fake-typing' in argv:
        key_delay_ms = 50 
    else:
        key_delay_ms = 0

    if '--fake-output' in argv:
        output = KeebdOutput.fake()
    else:
        output = KeebdOutput(key_delay_ms)

    ocr = FastOcr()
    button = Button(17)
    storage_path = Path("/tmp/piscanner/images")
    storage_path.mkdir(parents=True, exist_ok=True)
    app = App(storage_path, button, camera, inference, ocr, output, state_output, logger)

    await run_web_app(storage_path)
    await state_output.ready()
    while True:
        await asyncio.sleep(3600)

if __name__ == "__main__":
    asyncio.run(exec(sys.argv))

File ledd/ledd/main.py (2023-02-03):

#!/usr/bin/env python

# Daemon to listen on a socket and start LED patterns based on the character sent on the socket
# Starts up in a "pulsing power LED" mode
# We run at 100 Hz
from math import sin, pi
import os
import asyncio
import time
from pathlib import Path 
from .pca9685 import PCA9685
import toml


class PulsingLight:
    def __init__(self, clock_rate_hz, light_name, pulse_freq=3.0):
        self.t = 0
        self.pulse_freq = pulse_freq
        self.loop_length_s = 1.0/clock_rate_hz
        self.light_name = light_name

    def tick(self):
        """
        tick methods return a {'r': num, 'y': num, 'g': num} dict, in the
        assumption that leaving one out means "no change"
        num is in the range 0-1
        """
        value = (sin(self.t*2*pi*self.pulse_freq)+1.0)/2
        self.t += self.loop_length_s    
        return {self.light_name: value}

class DoublePulse:
    def __init__(self, clock_rate_hz, light_name, pulse_freq=3.0):
        self.t = 0
        self.pulse_freq = pulse_freq
        self.loop_length_s = 1.0/clock_rate_hz
        self.light_name = light_name

    def tick(self):
        freq_multiple =2*pi*self.pulse_freq
        value = (sin(self.t*freq_multiple) + sin(self.t*3*freq_multiple) + 2.0)/4
        self.t += self.loop_length_s    
        if value > 0.5:
            return {self.light_name: value}
        else:
            return {self.light_name: 0}

class SolidLight:
    def __init__(self, light_name, value=1.0):
        self.result = {light_name: value}

    def tick(self):
        return self.result

class PatternMaker:
    def __init__(self, pwm_refresh_rate_hz):
        self.pwm_refresh_rate_hz = pwm_refresh_rate_hz

    def pulsing(self, light_name, pulse_rate_hz):
        return PulsingLight(self.pwm_refresh_rate_hz, light_name, pulse_rate_hz)

    def solid(self, light_name, value=1.0):
        return SolidLight(light_name, value)

    def double_pulse(self, light_name, pulse_rate_hz):
        return DoublePulse(self.pwm_refresh_rate_hz, light_name, pulse_rate_hz)

    def off(self, light_name):
        return self.solid(light_name, 0.0)
    
def collect_patterns(patterns):
    result = {}
    for pattern in patterns:
        result.update(pattern.tick())
    return result

def apply_values(pwm, light_values):
    light_names = ['r', 'y', 'g']
    for i in range(len(light_names)):
        light_name = light_names[i]
        if light_name in light_values:
            pwm.duty(i, int(4095*light_values[light_name]))

async def handle_client(reader, writer):
    global states
    global selected_state
    new_state_name = (await reader.readline()).decode('utf-8').strip()
    if new_state_name in states:
        print("Selecting state", new_state_name)
        selected_state = new_state_name

def listen(socket_path):
    path = Path(socket_path)
    path.parent.mkdir(exist_ok=True, parents=True)
    loop = asyncio.get_event_loop()

    result = loop.run_until_complete(asyncio.start_unix_server(handle_client, path=socket_path))
    os.chmod(socket_path, 0o666)

async def state_loop(pwm):
    global states
    global selected_state

    while True:
        patterns = states[selected_state]
        apply_values(pwm, collect_patterns(patterns))
        await asyncio.sleep(1.0/pwm_refresh_rate_hz)

pwm_refresh_rate_hz = 100
patterns = PatternMaker(pwm_refresh_rate_hz)
states = {
    'start': [patterns.pulsing('r', 0.5), patterns.off('y'), patterns.off('g')],
    'ready': [patterns.solid('r', 1.0), patterns.off('y'), patterns.off('g')],
    'processing': [patterns.pulsing('y', 1.0), patterns.off('g')],
    'success': [patterns.off('y'), patterns.solid('g', 1.0)],
    'alert': [patterns.double_pulse('r', 80.0/60), patterns.off('y'), patterns.off('g')]
}
selected_state = 'start'

if __name__ == "__main__":
    pwm = PCA9685.get()
    pwm.freq(pwm_refresh_rate_hz)

    listen(toml.load("/etc/ledd.conf")['socket_path'])
    loop = asyncio.get_event_loop()
    loop.run_until_complete(state_loop(pwm))

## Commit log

2023-02-01 Explain the temporary embarrassing lack of CAD files
2023-02-01 Add the .step files for each version of the shell
    [piscanner-mk1.step, piscanner-mk2.step]
2023-02-01 Fix piscanner-mk1.step
    [piscanner-mk1.step]
2023-02-01 Add the mk1 stl
    [piscanner-mk1.stl]
2023-02-01 Add a description of the mk1 pi case mounting
2023-02-01 Add sd card slot detail
2023-02-01 Add the mk2 stl
    [piscanner-mk2.stl]
2023-02-01 Add a couple of the training data generation scripts
2023-02-02 Point at the il-keebd repository
2023-02-03 Add the LED service
2023-02-03 Switch to the right yolo variant
2023-02-06 Add the piscanner source
    [scanner-yolov4-tiny.cfg]
2023-02-10 Add conclusions and a couple more links
2023-03-20 Update README.md
    Cut down the `Patient ID QR Code` section
